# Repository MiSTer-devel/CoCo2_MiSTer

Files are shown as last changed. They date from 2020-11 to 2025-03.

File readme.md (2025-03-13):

# MiSTer Tandy Color Computer 2 (CoCo2)  and Dragon 32

Originally started by:

https://github.com/pcornier/coco2

Completeted by dshadoff, alanswx,  pcornier, shodge12, and theflynn49.
Regression tests by Kathleen.

### Tandy Color 2

This core implements a Tandy Color Computer 2 (CoCo2) including:
 * 64k Memory
 * 2 Analog Joysticks (with a swap feature)
 * Cassette Loading/Saving
 * Sound
 * Cartridge Support
 * Disk support

### Dragon 32 / 64

 * 32K Dragon32 or 64K Dragon64
 * 2 Analog Joysticks (with a swap feature)
 * Cassette Loading/Saving
 * Sound
 * Cartridge Support
 * Disk support

### ROMS

This core needs ROMS, that you may build from files you find easely on colorcomputerarchive (or elsewhere)

 * boot0.rom : 16k (CoCo2) : concatenation of extbas11.rom and bas12.rom, in this order.
 * boot1.rom : 16k (Dragon32) : copy of d32.rom
 * boot2.rom : 32k (Dragon64) concatenation of d64rom1.rom and d64rom2.rom in this order.
 * boot3.rom : 24k (Disk drivers) concatenation of disk11.rom, sdose8.rom (for D32) and sdose8.rom (for D64) again in this order.

You may use other components, these are just the ones we use to run the regression tests. You need to respect the location of the rom in the boot files, like you would respect the location of a rom chip on a motherboard.

Once you collected the needed files, you may run theses commands on your MiSTer to build the bootX.rom files :

 * cat extbas11.rom bas12.rom > /media/fat/games/CoCo2/boot0.rom
 * cp d32.rom  /media/fat/games/CoCo2/boot1.rom 
 * cat d64rom1.rom d64rom2.rom > /media/fat/games/CoCo2/boot2.rom
 * cat disk11.rom sdose8.rom sdose8.rom > /media/fat/games/CoCo2/boot3.rom

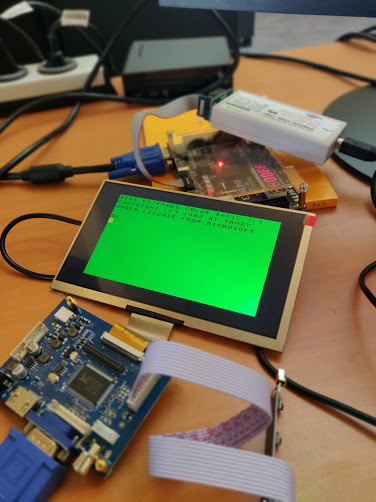
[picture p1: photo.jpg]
Coco2 running on the AX309


*Coco 2 running on a AX309 board*

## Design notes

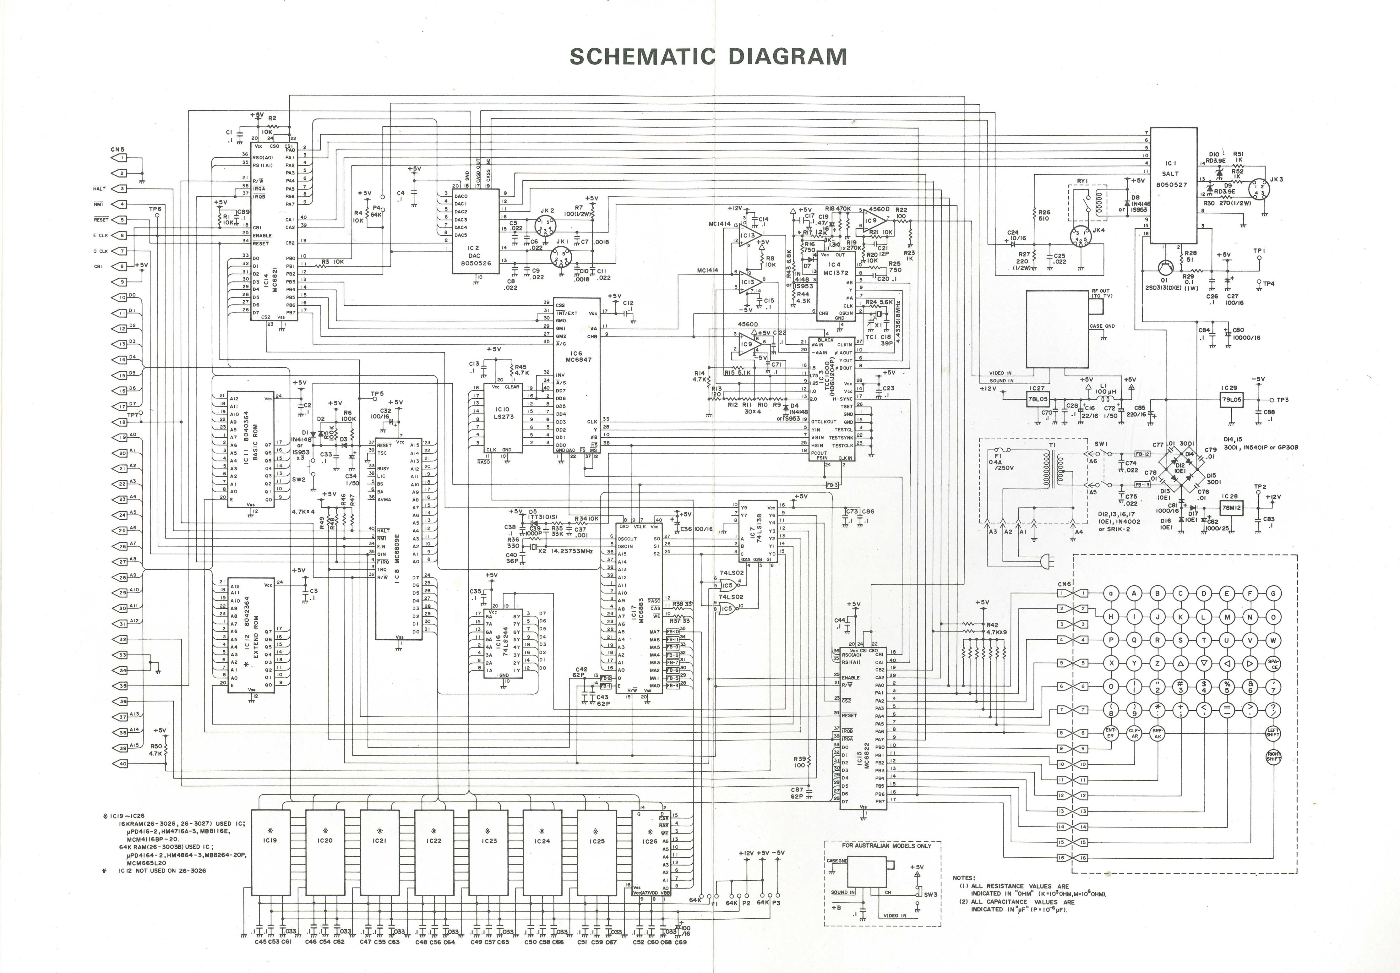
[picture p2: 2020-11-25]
doc/schematic.jpg

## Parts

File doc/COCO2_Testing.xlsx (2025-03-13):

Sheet: CoCo2
CoCo2 Compatibility Testing Spreadsheet |  |  |  |  | Version: | 3.01 |  |  |  |  |  |  | 2024-06-24
ID | Game / Program | Format |  |  | Load 20240605 | Load 20240622 | Load 20240629 | Load 20240701 | Load | Load | Load | Load 20250215 | Updated on | By | Remarks | Remarks 2 | Comments
 |  | Cart | Disk | Tape |  |  |  |  | 20241230 | 20250121 | 20250131
1 | 666 The Hounted House (2003) (Hofzets Chris) |  | X |  | Y |  |  |  |  | Y | Y | Y | 2025-02-09 | Kasurin
2 | 7 Card Stud (198x) (Tandy) |  | X |  | Y |  |  |  |  | Y | Y | Y | 2025-02-09 | Kasurin |  |  | 26-3074
3 | 7 Cards Stut (1983) (Tandy) | X |  |  | Y |  | Y | Y |  |  |  | Y | 2025-02-10 | Kasurin |  |  | 26-3074
4 | Adventure in Mythology (1985) (Saguard soft) |  | X |  | Y |  |  |  |  | Y | Y | Y | 2025-02-09 | Kasurin
5 | Andrea Coco (1985) (Saguard soft) |  | X |  | Y |  |  |  |  | Y |  | Y | 2025-02-09 | Kasurin
6 | Androne (1983) (Tandy) | X |  |  | Y |  | Y | Y |  |  |  | Y | 2025-02-09 | Kasurin | D-Pad OK | Red instead of orange (reltaed to VDG6847) | 26-3096
7 | Androne (1983) (Tandy) |  | X |  | Y |  |  |  |  | Y |  | Y | 2025-02-09 | Kasurin |  |  | 26-3096
8 | Arkanoid (1987) (Tandy) |  | X |  | Y |  |  |  |  | Y |  | Y | 2025-02-09 | Kasurin |  |  | 26-3043
9 | Arkanoid (1987) (Tandy) (Coco 1-2 version) | X |  |  | Y |  | Y | Y |  |  |  | Y | 2025-02-09 | Kasurin | D-Pad OK |  | 26-3043
10 | Art Gallery (1981) (Tandy) | X |  |  | Yx |  | Yx | Yx |  |  | Y | Y | 2025-02-11 | Kasurin | Save works now |  | 26-3061
11 | Atom (1983) (Tandy) | X |  |  | Y |  | Y | y |  |  |  | Y | 2025-02-10 | Kasurin |  |  | 26-3149
12 | Atom (1983) (Tandy) |  | X |  | Y |  |  |  |  | Y |  | Y | 2025-02-09 | Kasurin |  |  | 26-3149
13 | Audio Spectrum Analyzer (1981) (Steve Bjork) | X |  |  | Yx |  | Yx |  |  |  |  | Yx | 2025-02-10 | Kasurin | ADC Input OK output sound is bad | Hint : A/Q to activate de-activate audio out | 26-3156
14 | Backgamon (1980) (Tandy) | X |  |  | Y |  | Y | Y |  |  |  | Y | 2025-02-10 | Kasurin |  |  | 26-3059
15 | Basic Aid (1982) (Eigen Sustem) | X |  |  | Y |  | Y | Y |  |  |  | N | 2025-02-10 | Kasurin |  | Hint: CTRL key is bottom arrow
16 | Bedlam (1982) (Tandy) |  | X |  | Y |  |  |  |  | Y |  | Y | 2025-02-09 | Kasurin |  |  | 26-3312
17 | Bingo Math (1980) (Tandy) | X |  |  | Y |  | Y | Y |  |  |  | Y | 2025-02-10 | Kasurin | D-Pad OK |  | 26-3150
18 | Bingo Math (1983) (Tandy) |  | X |  | Y |  |  |  |  | Y |  | Y | 2025-02-09 | Kasurin |  |  | 26-3150
19 | Blackbeard's Island (1984) (Tom Mix Softw) |  | X |  | Y |  |  |  |  | Y |  | Y | 2025-02-09 | Kasurin
20 | Bridge Tutor (1983) (Tandy) |  | X |  | Y |  |  |  |  | Y |  | Y | 2025-02-09 | Kasurin |  |  | 26-3158
21 | Bridge Tutor I (1982) (Tandy) | X |  |  | Y |  | Y | Y |  |  |  | Y | 2025-02-10 | Kasurin |  |  | 26-3158
22 | Bustout (1981) | X |  |  | Y |  | Y | Y |  |  |  | Y | 2025-02-10 | Kasurin | D-Pad OK |  | 26-3056
23 | Caladuril - FOL (1987) (Diecom Products) |  | X |  | Y |  |  |  |  | Y |  | Y | 2025-02-09 | Kasurin | Save and load work :-)
24 | Canyon Climber (1982) (Tandy) |  | X |  | Yx |  |  | Y |  | Y |  | Y | 2025-02-09 | Kasurin | Glitches when move to next level | To be checked on real HW [Kb] | 26-3089
25 | Castle Guard (1981) (Tandy) | X |  |  | Y |  | Y | Y |  |  |  | Y | 2025-02-10 | Kasurin |  | Red instead of orange (reltaed to VDG6847) | 26-3079
26 | Castle Guard (1982) (Tandy) |  | X |  | Y |  |  |  |  | Y |  | Y | 2025-02-09 | Kasurin |  |  | 263079
27 | Cave Walker (1986) (Spectral Associates) |  | X |  | Y |  |  |  |  |  |  | Y | 2025-02-09 | Kasurin | OS-9 game. | Type DOS to start the game
28 | Cave Walker (1987) (Tandy) |  | X |  | Y |  |  |  |  |  |  | Y | 2025-02-09 | Kasurin | OS-9 game. | Type DOS to start the game | 26-3246
29 | Caves of the unwashed heaten (1996) |  | X |  | Y |  |  |  |  |  |  | Y | 2025-02-09 | Kasurin
30 | Caynon Climber (1989) | X | X |  | Yx |  | Yx |  |  |  |  | y | 2025-02-09 | Kasurin | Glitches when move to next level | To be checked on real HW [Kb] | 26-3089
31 | Checker King (1980) (Tandy) | X |  |  | Y |  | Y | Y |  |  |  | y | 2025-02-09 | Kasurin |  |  | 26-3055
32 | Checker King (1980) (Tandy) |  | X |  | Y |  |  |  |  |  |  | Y | 2025-02-09 | Kasurin |  |  | 26-3055
33 | Checkers (1986) (Young Richard) |  | X |  | Y |  |  |  |  |  |  | y | 2025-02-09 | Kasurin | Hint : cload "C for tape | Hint : cload "D for disk
34 | Chess (1980) (Tandy) |  | X |  | Y |  |  |  |  |  |  | Y | 2025-02-09 | Kasurin |  |  | 26-3050
35 | Chessd (1984) (Software Dynamicc) |  | X |  | Y |  |  |  |  |  |  | Y | 2025-02-09 | Kasurin
36 | Clowns & Ballons (1982) (Tandy) | X |  |  | Y |  | Y | Y |  |  |  | Y | 2025-02-09 | Kasurin |  | Red instead of orange (reltaed to VDG6847) | 26-3087
37 | Clowns & Ballons (1982) (Tandy) |  | X |  | Y |  |  |  |  |  |  | Y | 2025-02-09 | Kasurin |  |  | 26-3087
38 | Color Backgamon (1980) (Tandy) |  | X |  | Y |  |  |  |  |  |  | Y | 2025-02-09 | Kasurin |  |  | 26-3059
39 | Color Baseball (1980) (Tandy) | X |  |  | Y |  | Y | Y |  |  |  | Y | 2025-02-10 | Kasurin |  |  | 26-3095
40 | Color Cubes (1981) (Tandy) | X |  |  | Y |  | Y | Y |  |  |  | Y | 2025-02-10 | Kasurin |  |  | 26-3075
41 | Color Cubes (1981) (Tandy) |  | X |  | Y |  |  |  |  |  |  | Y | 2025-02-09 | Kasurin |  |  | 26-3075
42 | Color File (1981) (Tandy) | X |  |  | Y |  | Y | Y |  |  |  | Y | 2025-02-10 | Kasurin | Load and save from tape works ! |  | 26-3103
43 | Color File II (1986) (Tandy) | X |  |  | Y |  | Y | Y |  |  |  | Y | 2025-02-10 | Kasurin | Load and save from tape works ! | Hint: HOME + 1,2,3….. for selection | 26-3110
44 | Color Forth (1981) (Microworks) | X |  |  | Y |  | Y | y |  |  |  | Y | 2025-02-10 | Kasurin
45 | Color Logo (1983) (Tandy) | X |  |  | Y |  | Y | Y |  |  |  | Y | 2025-02-10 | Kasurin | Save doesn't work |  | 26-2722
46 | Color Robot Battle (1981) (Tandy) | X |  |  | Y |  | Y | Y |  |  |  | Y | 2025-02-10 | Kasurin | Seems to work | Red instead of orange (reltaed to VDG6847) | 26-3070
47 | Color Scripsit (1981) (Tandy) | X |  |  | Yx |  | Yx | Yx |  |  |  | Y | 2025-02-10 | Kasurin | Load and save from tape works ! | Hint: ESC+1 for main menu | 26-3105
48 | Color Scripsit II (1986) (Tandy) | X |  |  | Yx |  | Yx | Yx |  |  |  | Y | 2024-07-02 | Kasurin |  | No experience with this software | 26-3109
49 | Conquering Armies (1988) (Mitchell Soft.) |  | X |  | N |  |  |  |  | N | Y | Y | 2025-02-09 | Kasurin | Seems to be working | No experience with this software
50 | Cosmic Crusader (Blaby) (Coco Port) |  | X | X |  |  | N | N |  |  | Y | Y | 2025-02-02 | Kasurin | Disk seems to be working fine | Tape to be tested
51 | Crosswords (1981) (Tandy) | X |  |  | Y |  | Y | Y |  |  |  | Y | 2025-02-10 | Kasurin |  |  | 26-3082
52 | Cyrus Chess (1982) (Tandy) |  | X |  | Y |  |  |  |  |  |  | Y | 2025-02-09 | Kasurin |  |  | 26-3064
53 | Cyrus World Class Chess (1983) (Tandy) | X |  |  | Y |  | Y | Y |  |  |  | Y | 2025-02-10 | Kasurin |  |  | 26-3064
54 | Dallas Quest (1984 (Tandy) |  | X |  | Y |  |  |  |  |  |  | Y | 2025-02-09 | Kasurin |  |  | 26-3294
55 | Demolition Derby (1984) (Tandy) | X |  |  | Y |  | Y |  |  |  |  | Y | 2025-02-10 | Kasurin |  | Red instead of orange (reltaed to VDG6847) | 26-3044
56 | Demon Attack (1984) (Tandy) | X |  |  | Y |  | Y |  |  |  |  | Y | 2025-02-10 | Kasurin |  | Red instead of orange (reltaed to VDG6847) | 26-3099
57 | Demon Attack (1984) (Tandy) |  | X |  | Y |  |  |  |  |  |  | Y | 2025-02-09 | Kasurin |  |  | 26-3099
58 | Desert Rider (1984) (Tandy) |  | X |  | N |  |  |  | Yx | Yx | Yx | Yx | 2025-02-02 | Kasurin | Works but vertical position issue | when jumping 24-01-2025 | 26-3292
59 | Diagnostics (1980) (Tandy) | X |  |  | Y |  | Y |  |  |  |  | Y | 2025-02-10 | Kasurin |  |  | 26-3019
60 | Diagnostics v2.0) (1982) (Tandy) | X |  |  | Y |  | Y |  |  |  |  | Y | 2025-02-10 | Kasurin |  |  | 26-3019
61 | Dino Wars (1980) (Tandy) |  | X |  | Y |  |  |  |  |  |  | Y | 2025-02-10 | Kasurin |  |  | 26-3057
62 | Dinowars (1981) (Tandy) | X |  |  | Y |  | Y |  |  |  |  | Y | 2025-02-10 | Kasurin |  |  | 26-3057
63 | Direct Connect Model Pak (1985) (Tandy) | X |  |  | Y |  | Y |  |  |  |  | Y | 2025-02-10 | Kasurin | Supposed to be OK | No ways to test | 26-2228
64 | Don-Pan (1984) (Tandy) | X |  |  | Y |  | Y |  |  |  |  | Y | 2025-02-10 | Kasurin |  |  | 26-2228
65 | Donu Dilemma (1987) (Marentes, Nikolas) |  | X |  | Y |  |  |  |  |  |  | Y | 2025-02-09 | Kasurin |  |  | 26-9649
66 | Doodle Bug (1982) (Computer Ware) | X |  |  | Y |  | Y |  |  |  |  | Y | 2025-02-10 | Kasurin |  | Red instead of orange (reltaed to VDG6847)
67 | Doodle Bug (1982) (Computer Ware) (Buff) | X |  |  | Y |  | Y |  |  |  |  | Y | 2025-02-10 | Kasurin
68 | Doodle Bug (1982) (Computer Ware) (Green) | X |  |  | Y |  | Y |  |  |  |  | Y | 2025-02-10 | Kasurin
69 | Doubleback (1982) (Tandy) | X |  |  | Y |  | Y |  |  |  |  | Y | 2025-02-10 | Kasurin |  | Red instead of orange (reltaed to VDG6847) | 26-3091
70 | Doubleback (1982) (Tandy) |  | X |  | Yx |  |  |  | Y | Y |  | Y | 2025-02-09 | Kasurin |  |  | 26-3091
71 | Dounwland (1984) (Tandy) |  | X |  | Y |  |  |  |  |  |  | Y | 2025-02-09 | Kasurin |  |  | 26-3046
72 | Downloand v1,0 (1983) (Tandy) | X |  |  | Y |  |  |  |  |  |  | Y | 2025-02-10 | Kasurin |  | Red instead of orange (reltaed to VDG6847) | 26-3046
73 | Downloand v1,1 (1983) (Tandy) | X |  |  | Y |  |  |  |  |  |  | Y | 2025-02-10 | Kasurin |  | Red instead of orange (reltaed to VDG6847) | 26-3046
74 | Dragon fire (1984) (Tandy) | X |  |  | N |  | Y | Y | y | y |  | Y | 2025-02-10 | Kasurin | Corrupted graphics [20240605] | Runs fine with [20240629] | 26-3098
75 | Dragonfire (1982) (Tandy) |  | X |  | N |  |  | Y | y | y |  | Y | 2025-02-09 | Kasurin | Corrupted graphics [20240605] | Runs fine with [20240701] | 26-3098
76 | Dungeons of Daggorath (1982) (Tandy) | X |  |  | Y |  | Y |  |  |  |  | Y | 2025-02-10 | Kasurin |  | Red instead of orange (reltaed to VDG6847) | 26-3093
77 | EDTASM+ (1982) (Tandy) | X |  |  | Y |  | Y |  |  |  |  | Y | 2025-02-10 | Kasurin |  |  | 26-3250
78 | Facemaker (1984) (Spinnaker) | X |  |  | Y |  | Y |  |  |  |  | Y | 2025-02-10 | Kasurin |  |  | 26-3166
79 | Flight Simulator I (1984) (Tandy) |  | X |  | Y |  |  |  |  |  |  | Y | 2025-02-09 | Kasurin | Seems to work | No experience with this game | 26-3108
80 | Football (1980) (Tandy) | X |  |  | Y |  | Y |  |  |  |  | Y | 2025-02-10 | Kasurin | Seems work | No experience with this game | 26-3053
81 | football (1980) (Tandy) |  | X |  | Y |  |  |  |  |  |  | Y | 2025-02-09 | Kasurin |  |  | 26-3053
82 | Fraction Fever (1984) (Tandy) | X |  |  | Yx |  | Yx |  | Yx | Yx | Yx | YX | 2025-02-10 | Kasurin | Works with kbd, but not with joystick |  | 26-3169
83 | Galactic Attack (1982) (Tandy) | X |  |  | Y |  | Y |  |  |  |  | Y | 2025-02-10 | Kasurin |  |  | 26-3066
84 | Ghana Bwana (1984) (Tandy) |  | X |  | Y |  |  |  |  |  |  | Y | 2025-02-09 | Kasurin |  |  | 26-3293
85 | Gin Champion (1982) (Tandy) | X |  |  | Y |  | Y |  |  |  |  | Y | 2025-02-10 | Kasurin |  |  | 26-3083
86 | Gin Champion (1982) (Tandy) |  | X |  | Y |  |  |  |  |  |  | Y | 2025-02-09 | Kasurin |  |  | 26-3083
87 | Gomoku-Renju (1983) (Tandy) | X |  |  | Y |  | Y |  |  |  |  | Y | 2025-02-10 | Kasurin |  |  | 26-3069
88 | Gomoku-Renju (1983) (Tandy) |  | X |  | Y |  |  |  |  |  |  | Y | 2025-02-09 | Kasurin |  |  | 26-3069
89 | Graphic Pak (1982) (Tandy) | X |  |  | Yx |  | Yx |  |  |  |  | Y | 2024-07-01 | Kasurin | Load and save from tape works ! |  | 26-3157
90 | Handyman (1981) (Tandy) | X |  |  | Y |  | Y |  |  |  |  | Y | 2025-02-10 | Kasurin |  |  | 26-3154
91 | Kids on Keys (1984) (Spinnaker) | X |  |  | Y |  | Y |  |  |  |  | Y | 2025-02-10 | Kasurin |  | Red instead of orange (reltaed to VDG6847) | 26-3167
92 | Kindercomp (1984) (Spinnaker) | X |  |  | Y |  | Y |  |  |  |  | Y | 2024-07-01 | Kasurin |  |  | 26-3168
93 | Klendathu (198x) (Tandy) |  | X |  | N |  |  |  | N | N | Y | Y | 2025-02-09 | Kasurin | Hint : HOME to start the game |  | 26-2567
94 | Madness and the Minotaur (1982) (Tandy) |  | X |  | Y |  |  |  |  |  |  | Y | 2025-02-09 | Kasurin |  |  | 26-3313
95 | Math Tutor (1988) (Tandy) | X |  |  | N |  | N |  | N | N | N | N | 2025-02-10 | Kasurin | Keys not respondig / Wrong colors | Red instead of orange (reltaed to VDG6847) | 26-3148
96 | Mega-Bug (1982) (Tandy) | X |  |  | Y |  | Y |  |  |  |  | Y | 2025-02-11 | Kasurin |  | Red instead of orange (reltaed to VDG6847) | 26-3076
97 | Micro Chess v2.0 (1980) (Tandy) | X |  |  | Y |  | Y |  |  |  |  | Y | 2025-02-11 | Kasurin |  |  | 26-3050
98 | Micro Painter (1982) (Tandy) | X |  |  | Y |  | Y |  |  |  |  | Y | 2024-07-01 | Kasurin |  |  | 26-3077
99 | Microbes (1981) (Tandy) | X |  |  | Y |  | Y |  |  |  |  | Y | 2025-02-11 | Kasurin |  | Red instead of orange (reltaed to VDG6847) | 26-3085
100 | Microbes (1981) (Tandy) |  | X |  | Y |  |  |  |  |  |  | Y | 2025-02-09 | Kasurin |  |  | 26-3085
101 | Mind-Roll (1989) (Tandy) |  | X |  | Y |  |  |  |  |  |  | Y | 2025-02-09 | Kasurin |  |  | 26-3100
102 | Monster Maze (1981) (Tandy) |  | X |  | Y |  |  |  |  |  |  | Y | 2025-02-09 | Kasurin |  |  | 26-3081
103 | Monster Maze (1983) (Tandy) | X |  |  | Y |  | Y |  |  |  |  | Y | 2025-02-11 | Kasurin |  | Red instead of orange (reltaed to VDG6847) | 26-3081
104 | Music (1980) (Tandy) | X |  |  | Y |  | Y |  |  |  |  | Y | 2025-02-11 | Kasurin |  |  | 26-3151
105 | Nerble Force (Computeware) |  | X |  |  |  | Y | Y |  |  |  | Y | 2025-02-11 | Kasurin
106 | One On One (1983) (Tandy) |  | X |  | Y |  |  |  |  |  |  | Y | 2025-02-09 | Kasurin |  |  | 26-3288
107 | Orchestra 90-CC (1984) (Tandy) | X |  |  | Y |  | Y |  |  |  |  | Y | 2025-02-11 | Kasurin | Start | No experience with this program | 26-3143
108 | Panic Button (1983) (Tandy) | X |  |  | Y |  | Y |  |  |  |  | Y | 2025-02-11 | Kasurin |  | Red instead of orange (reltaed to VDG6847) | 26-3147
109 | Panic Button (1985) (Tandy) |  | X |  | Y |  |  |  |  |  |  | Y | 2025-02-09 | Kasurin
110 | Pegasus and the phantom rider (1985) |  | X |  | Y |  |  |  |  |  |  | Y | 2025-02-09 | Kasurin
111 | Personal Finance (1980) (Tandy) | X |  |  | Yx |  | Yx |  |  |  | Yx | Yx | 2025-02-11 | Kasurin | Load and save data don't seem to work | Need more testing to confirm | 26-3101
112 | Personal Finance II (1983) (Tandy) | X |  |  | Yx |  | Yx |  |  |  |  | Yx | 2025-02-11 | Kasurin | Load and save data don't seem to work | Need more testing to confirm | 26-3106
113 | Pinball (1980) (Tandy) | X |  |  | Y |  | Y |  |  |  |  | Y | 2025-02-11 | Kasurin |  | Hint : Need two Joysticks to play | 26-3052
114 | Pinball (1980) (Tandy) |  | X |  | y |  |  |  |  |  |  | Y | 2025-02-09 | Kasurin |  | Hint : Need two Joysticks to play | 26-3052
115 | Pitfall II (1985) (Tandy) |  | X |  | Y |  |  |  |  |  |  | y | 2025-02-09 | Kasurin |  | Had to use the ALT2 version | 26-3287
116 | Polaris (1981) (Tandy) | X |  |  | Y |  | Y |  |  |  |  | Y | 2025-02-11 | Kasurin |  | Hint : ZXC for fire + joystick | 26-3065
117 | Polaris (1981) (Tandy) |  | X |  | Y |  |  |  |  |  |  | y | 2025-02-09 | Kasurin |  | Hint : ZXC for fire + joystick | 26-3065
118 | Poltergeist (1982) (Tandy) | X |  |  | Y |  | Y |  |  |  |  | Y | 2025-02-11 | Kasurin |  | Red instead of orange (reltaed to VDG6847) | 26-3073
119 | Popcorn (1981) (Tandy) | X |  |  | Y |  | Y |  |  |  |  | Y | 2025-02-11 | Kasurin |  | Red instead of orange (reltaed to VDG6847) | 26-3090
120 | Pooyan |  | X |  |  |  |  |  |  |  |  | y | 2025-02-09 | Kasurin
121 | Project Nebula (1981) (Tandy) | X |  |  | Y |  | Y |  |  |  |  | Y | 2025-02-11 | Kasurin |  |  | 26-3063
122 | Quasar Commander (1980) (Tandy) | X |  |  | Y |  | Y |  |  |  |  | Y | 2025-02-11 | Kasurin |  | Hint : Needs to joysticks to play | 26-3051
123 | Reactoid (1983) (Tandy) | X |  |  | Y |  | Y |  |  |  |  | Y | 2025-02-11 | Kasurin |  | Red instead of orange (reltaed to VDG6847) | 26-3092
124 | Roman Checkers (1981) (Tandy) | X |  |  | Y |  | Y |  |  |  |  | Y | 2025-02-11 | Kasurin |  |  | 26-3071
125 | SDS80C (1981) (The Micro Works) | X |  |  | Y |  | Y |  |  |  |  | Y | 2025-02-11 | Kasurin
126 | Shooting Gallery (1982) (Tandy) | X |  |  | Y |  | Y |  |  |  |  | Y | 2025-02-11 | Kasurin |  | Red instead of orange (reltaed to VDG6847) | 26-3088
127 | Skiing (1981) (Tandy) | X |  |  | Y |  | Y |  |  |  |  | Y | 2025-02-11 | Kasurin |  |  | 26-3058
128 | Slay The Nereis (1983) (Tandy) | X |  |  | Y |  | Y |  |  |  |  | Y | 2025-02-11 | Kasurin |  | Red instead of orange (reltaed to VDG6847) | 26-3086
129 | Soko Ban (1988) (Tandy) | X |  |  | Y |  | Y |  |  |  |  | Y | 2025-02-11 | Kasurin |  | Red instead of orange (reltaed to VDG6847) | 26-3161
130 | Space Assault (1981) (Tandy) | X |  |  | Y |  | Y |  |  |  |  | Y | 2025-02-11 | Kasurin |  |  | 26-3060
131 | Spectaculator (1983) (Tandy) | X |  |  | Y |  | Y |  |  |  |  | Y | 2025-02-11 | Kasurin |  |  | 26-3104
132 | Spidercide (1983) (Tandy) | X |  |  | Y |  | Y |  |  |  |  | Y | 2024-07-01 | 2025-02-11 |  | Red instead of orange (reltaed to VDG6847) | 26-3049
133 | Starblaze (1983) (Tandy) | X |  |  | Y |  | Y |  |  |  |  | Y | 2025-02-11 | Kasurin |  |  | 26-3094
134 | Stellar Lifeline (1983) (Tandy) | X |  |  | Y |  | Y |  |  |  |  | Y | 2025-02-11 | Kasurin |  | Red instead of orange (reltaed to VDG6847) | 26-3047
135 | Super Logo (1984) (Tandy) | X |  |  | Y |  | Y |  |  |  |  | Y | 2025-02-11 | Kasurin |  | Hint : Artifact to be disabled | 26-2717
136 | Temple of ROM (1984) (Tandy) | X |  |  | Y |  | Y |  |  |  |  | y | 2025-02-11 | Kasurin |  | Red instead of orange (reltaed to VDG6847) | 26-3045
137 | Tennis (1981) (26-3080) (Tandy) | X |  |  | Y |  | Y |  |  |  |  | Y | 2025-02-11 | Kasurin |  |  | 26-3080
138 | TypeMate (1988) (Tandy) | X |  |  | N |  | N |  | N | N | N | N | 2025-02-11 | Kasurin | Keys not respondig as they should |  | 26-3155
139 | Typing Tutor (1980) (Tandy) | X |  |  | Y |  | Y |  |  |  |  | Y | 2025-02-11 | Kasurin |  |  | 26-3152
140 | Videotex v1,1 (1981) (Tandy) | X |  |  | Y |  | Y |  |  |  |  | Y | 2025-02-11 | Kasurin | Supposed to be OK | No experience with this program | 26-2222
141 | Videotex v1,2 (1981) (Tandy) | X |  |  | Y |  | Y |  |  |  |  | Y | 2025-02-11 | Kasurin | Supposed to be OK | No experience with this program | 26-2222
142 | Wildcatting (1982) (Tandy) | X |  |  | Y |  | Y |  |  |  |  | Y | 2025-02-11 | Kasurin |  |  | 26-3067
143 | OS9 Level 1 V 01.00.00 |  | X |  |  |  |  |  |  |  |  | Y | 2025-03-12 | SRH
144 | NitrOS-9/6809 Level 1 V3.30 for CoCo1 |  | X |  |  |  |  |  |  |  |  | Y | 2025-03-12 | SRH
145 | NitrOS-9/6809 Level 1 V3.30 for CoCo2 |  | X |  |  |  |  |  |  |  |  | Y | 2025-03-12 | SRH

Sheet: Dragon32
CoCo2 Compatibility Testing Spreadsheet |  | Version: | 3.01 |  | 2024-06-24
ID | Format / Name | Cat n° | Load 20250131 | Load 20250215 | Updated on | By | Remarks | Remarks 2
1 | DSK / Airball |  | Y | Y | 2025-02-18 | Kasurin
2 | DSK / Balldozer |  | Y | Y | 2025-02-18 | Kasurin
3 | CAS / 4D Romik Cube |  |  | Y | 2025-02-18 | Kasurin
4 | CAS / Adventure 2 - Jerusalem |  |  | Y | 2025-02-18 | Kasurin
5 | CAS / Air Assault |  |  | Y | 2025-02-18 | Kasurin
6 | CAS / Alcatraz |  |  | Y | 2025-02-18 | Kasurin
7 | CAS / Amazing |  |  | Y | 2025-02-18 | Kasurin
8 | DSK / Machine Languae Tutorial |  |  | Y | 2025-02-19 | Kasurin | Need a complete reload of the core otherwise the screen is not OK at restart
9 | CAS / Phantom Slayer( (Med System) |  |  | N | 2025-02-20 | Kasurin | Load but ST ERROR after EXEC
10 | CAS / Backtrack (198x) |  |  | Y | 2025-02-20 | Kasurin
11 | CAS / The Bells (1984) |  |  | Yx | 2025-02-20 | Kasurin | Works with some glitches | Need SHIFT+Z/W for left/right instead od Z/W
12 | CAS / Chuckie egg (1983) |  |  | Y | 2025-02-20 | Kasurin
13 | CAS / Ice Castles |  |  | Y | 2025-02-20 | Kasurin | Works with joystick :-)
14 | CAS / Space Invaders |  |  | Y | 2025-02-20 | Kasurin
15 | CAS / Time Bandid |  |  | N | 2025-02-20 | Kasurin | Freeze during loading
16 | CAS / Tube way army |  |  | Yx | 2025-02-20 | Kasurin | Does not work with joystick | Strange key mapping
17 | CAS / UGH! |  |  | Y | 2025-02-20 | Kasurin | Works with joystick :-)
18 | DSK / Interplanetary Trader |  |  | y | 2025-03-07 | Kasurin
19 | DSK / Execution |  |  | Y | 2025-03-07 | Kasurin
20 | DSK / Wumpus Mantion |  |  | Y | 2025-03-07 | Kasurin
21 | DSK / Wipeout |  |  | Y | 2025-03-07 | Kasurin
22 | DSK / Frogger |  |  | Y | 2025-03-07 | Kasurin
23 | DSK / Flipper |  |  | Y | 2025-03-07 | Kasurin
24 | DSK / Raceball |  |  | Y | 2025-03-07 | Kasurin
25 | DSK / Cuthbert in the jungle |  |  | Y | 2025-03-07 | Kasurin
26 | DSK / Pedro |  |  | Y | 2025-03-07 | Kasurin
27 | DSK / Transylvanian Tower |  |  | Yx | 2025-03-07 | Kasurin | Seems to be working | Did not find how to control the player
28 | DSK / Danger Ranger |  |  | Y | 2025-03-07 | Kasurin
29 | DSK / Shock Trooper |  |  | Y | 2025-03-07 | Kasurin
30 | DSK / Speed Racer |  |  | Y | 2025-03-07 | Kasurin
31 | DSK / Storm Arrows |  |  | Yx | 2025-03-07 | Kasurin | Car moves always to right | Like if Joy is not centered
32 | DSK / Chuckie Egg |  |  | Y | 2025-03-07 | Kasurin
33 | DSK / Moon Hopper |  |  | Yx | 2025-03-07 | Kasurin | Not possible to move L&R
34 | DSK / The Phantom Slayer |  |  | Y | 2025-03-07 | Kasurin
35 | DSK / Hunchback |  |  | Yx | 2025-03-07 | Kasurin | Strange diagonal lines in game
36 | DSK / Morocco GP |  |  | Y | 2025-03-07 | Kasurin
37 | DSK / Juniors Revenge |  |  | Y | 2025-03-07 | Kasurin
38 | DSK / U X B |  |  | Y | 2025-03-07 | Kasurin | Seems to be working | No experience with this game
39 | DSK / Intergalactic force |  |  | Y | 2025-03-07 | Kasurin
40 | DSK / Dragon Hawk |  |  | Y | 2025-03-07 | Kasurin
41 | DSK / Cuthbert in space |  |  | Y | 2025-03-07 | Kasurin
42 | DSK / Beanstalker |  |  | y | 2025-03-07 | Kasurin
43 | DSK / Creazy Painter |  |  | Y | 2025-03-07 | Kasurin
44 | DSK / Talking Android Attack |  |  | Y | 2025-03-07 | Kasurin
45 | DSK / Rommels Revenge |  |  | Y | 2025-03-07 | Kasurin | Didn't find with kybd how to move forward and backward | Works with Joystick however
46 | DSK / Cashman |  |  | Y | 2025-03-07 | Kasurin
47 | DSK / The King |  |  | Y | 2025-03-07 | Kasurin
48 | DSK / Eddy Steady Go |  |  | N | 2025-03-07 | Kasurin | Does not launch
49 | DSK / TeaTime |  |  | Y | 2025-03-07 | Kasurin
50 | DSK / Cuthbert in golden chalice |  |  | Yx | 2025-03-07 | Kasurin | Works but 2 lines which shouldn't be there | at the top left and righ of the screen during the game
51 | DSK / Starman Jones |  |  | Y | 2025-03-07 | Kasurin
52 | DSK / Robin hood |  |  | Y | 2025-03-07 | Kasurin
53 | DSK / Time Bandit |  |  | Y | 2025-03-07 | Kasurin
54 | DSK / Space Wrek |  |  | Y | 2025-03-07 | Kasurin
55 | DSK / Pitfiend |  |  | Y | 2025-03-07 | Kasurin
56 | DSK / BoulderCrash |  |  | Y | 2025-03-07 | Kasurin
57 | DSK / Chambers |  |  | Y | 2025-03-07 | Kasurin
58 | DSK / Kamacarzy |  |  | Y | 2025-03-07 | Kasurin
59 | DSK / Tube Way Army |  |  | Y | 2025-03-07 | Kasurin
60 | DSK / Wizards Quest |  |  | Y | 2025-03-07 | Kasurin
61 | DSK / Dragon Chess |  |  | Y | 2025-03-07 | Kasurin
62 | DSK / Dungeon Raid |  |  | Y | 2025-03-07 | Kasurin
63 | DSK / Stone Raider II |  |  | Y | 2025-03-07 | Kasurin
64 | DSK / Draconian |  |  | Y | 2025-03-07 | Kasurin
65 | DSK / Moon Cresta |  |  | Y | 2025-03-07 | Kasurin
66 | DSK / Blochead |  |  | N | 2025-03-07 | Kasurin | Doesn't go further than color selection
67 | DSK / BoulderCrash II |  |  | Y | 2025-03-07 | Kasurin
68 | DSK / Buzzard bait |  |  | Y | 2025-03-07 | Kasurin
69 | DSK / Zaxxon |  |  | Y | 2025-03-07 | Kasurin
70 | DSK / Guardian |  |  | N | 2025-03-07 | Kasurin | Playable but graphic garbage
71 | DSK / Whirlybird run |  |  | Y | 2025-03-07 | Kasurin
72 | DSK / Paper Route |  |  | Y | 2025-03-07 | Kasurin
73 | DSK / Marble Maze |  |  | Y | 2025-03-07 | Kasurin
74 | DSK / Color Tenis |  |  | Y | 2025-03-07 | Kasurin

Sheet: Dragon64
CoCo2 Compatibility Testing Spreadsheet |  | Version: | 3.01 | 2024-06-24
ID | Format / Name | Cat n° | Load 20250215 | Updated on | By | Remarks | Remarks 2
1 | NitrOS-9/6809 Level 1 V3.30 for Dragon64 |  | Y | 2025-03-11 | SRH | You may want to turn artifacts off

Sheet: Version History
CoCo2 Compatibility Testing Spreadsheet |  |  |  | Version: | 3.01 | 2024-06-24
Version | Date | Comment
3.01 | 2024-06-24 | Headers slaved to CoCo2_Cart, version hostory added, Version and Version_Date derrived from Version History table
Current Version: |  | 3.01 | 2024-06-24

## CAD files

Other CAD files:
ints.stp
stp1.stp

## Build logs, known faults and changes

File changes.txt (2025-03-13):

CoCo2_20250215 - 001 RC6
1:	Recursion testing spreadsheet completed.
2:	Updated MiSTer template
3:	Added Daily Build Number.  Note sys/build_num.tcl changed to add this functionality.
	Updating the template in the future will need to restore this version to prevent
	the loss of this functtion.
4:  Changed back to Cycle accurate 09
5:  Fixed Timer [The FDC cartridge does not generate a FIRQ when asserted.  This was fixed..]
6:  Double speed poke in the SAM via SAM registers coded.  Video sync at high speed fixed
7:  FDC changed to use system clk and divide to 8 Mhz changed to /6.  FIRQ generation
    for Dragon, qualified enabled only in Dragon configurations.
8:	Fixed some incorrect menu subscript duplications
9:	Added Cassette Save
10: Added minor delay to 1793 interrupt to fix dragon os9 problem.  Also removed HALT from
    dragon FDC.
11: Nitro OS9 working on CoCo & Dragon64.
12:	ROMs removed from .rbf.  Instructions for the creation in the README.MD file.  Code added
    to show 'NO ROMS' on output video without roms being found on load of core.

To Do...

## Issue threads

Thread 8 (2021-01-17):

Controller issue

Televicious, 2021-01-17:
I've tried several controllers and up an down do not work. Running color baseball. Also, color baseball is the only cart that loads dungeon of dagorath does not. The work in the coco3 core, though that care wo"t read disk images properly.

alanswx, 2021-01-17:
Make sure you go completely through the analog joystick setup. This core uses an analog joystick. Also check to see if the analog joystick works on another analog core like food fight or lunar lander.

dshadoff, 2021-01-17:
It's actually a problem that the analog stick setup is misleading; as you sequence through the controller setup, analog stick setup takes place after mouse settings.

sorgelig, 2021-01-17:
How it's misleading?

dshadoff, 2021-01-17:
I will work on D-Pad emulation of analog joysticks, as analog joystick setup is a common issue.

With respect to the other compatibility concerns, we can look into the Dungeons of Daggorath at some point.
This core does not currently support disk, or CoCo3 hardware, so please be careful about compatibility.

dshadoff, 2021-01-18:
I ran the Dungeons of Daggorath cart from the "TRS-80 Color Computer Archive" successfully on the existing core.
Not sure what problems you are seeing.

That game is, however, an adventure game where you need to type specific commands, so it isn't obvious how to play if you're not already familiar with it.

Also, I have submitted a pull request to use D-pad in case you are still having difficulties setting up the analog stick.  It will be part of the next release when it becomes available.

Televicious, 2021-01-18:
It was not loading for me even after resetting. The .ccc was from the same
archive. I'll redownload it and try again incase the file was somegow
corrupted. Good to know on the analog pad. I can use an analog stick. I
thought this project to be similar to the coco3 core that was released on
mister last spring. That had the dpad emulation already.

On Sun, Jan 17, 2021, 11:04 PM David Shadoff <notifications@github.com>
wrote:

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

dshadoff, 2021-01-18:
That CoCo3 core has several years of development behind it; this core was built in the fall independently, and doesn't have all the features at this time.

The "Reset" on this core is not 100% perfect; indeed, it isn't perfect on the original hardware either - but this core needs to stabilize the reset a bit more than it currently is.  If reset (or insert cartridge) doesn't work for you, try another reset.  It is a bit finicky at the moment.

dshadoff, 2021-01-25:
The version with the d-pad emulation of analog pad is now released; I'm hoping by now you have also straightened out your issues setting up the analog pad, and have tested it works - for example, with the "Diagnostics 2.0" cartridge.

I would request that you close the issue if this is the case.
If you have other issues, please open separate issues in the log so that they can be tracked properly.

Televicious, 2021-01-25:
Oh awesome. Yes, it works great. Thank you.

Closed 2021-01-25.

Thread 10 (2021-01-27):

Flickering picture since the last update

Milongero71, 2021-01-27:
Hello,
with the last update of the cores
Atari ST, GameBoy, Coco2 and ZX Spectrum I have now a flicker in the picture and OSD. I used a LCD monitor via the analog output on the I/O board. I have activated the scaler.
I have tested the previous versions and they give a clean picture.

sorgelig, 2021-01-27:
will be fixed soon

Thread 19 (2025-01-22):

I propose to merge 022024-Changes into master

theflynn49, 2025-01-22:
@shodge12

Hello.
The title says it all.
I think this branch has reached its goals (but only shodge12 can confirm this), and the branch is getting cumbersome.
Reset, video clock, FDC are fixed, at least to some extent, the master clock change to 57Mhz seems to work fine.

What's left to do in this core in my opinion is to boot OS9 and NOS9 (today it freezes, so there must be more bugs in the fdc), add save states (to help debugging, but everyone likes them anyway), make some cleaning and warning removing, (and maybe add a skin).

So if someone feels competent to help with this decision, you're welcome :D  ...

Rgds
jF

shodge12, 2025-01-23:
@theflynn49

Not sure what is defined by cumbersome unless someone else wants to work the remaining issues.

The branch indeed makes some largescale updates to the coco2 core, but while the majority of the goals were achieved, 1 goal and 1 interrupt problem kept the merge from occurring in the 8/24 time frame.   The following is the current change log for the branch:

CoCo2_20240701 - 008
1:	Prelim recursion testing spreadsheet completed.
2:	Updated MiSTer template
3:	Added Daily Build Number.  Note sys/build_num.tcl changed to add this functionality.
	Updating the template in the future will need to restore this version to prevent
	the loss of this functtion.
4:  Change back to Cycle accurate 09
5:  Fixed Timer [The FDC cartridge does not generate a FIRQ when asserted.  This was fixed..]
6:  Preliminary double speed poke in the SAM via SAM registers coded.  WIP
7:  FDC changed to use system clk and divide to 8 Mhz changed to /6.  FIRQ generation
    for Dragon, qualified enabled only in Dragon configurations.

Issues:
1:  Highspeed pokes may be backwards.  Full 1.78Mhz seems to have a video issue.
2:  Timer basic function is not working... [interrupt processing issue]

To Do...
1:    Add Cassette Save
2:    Get FDC working for dragon (edited)

Issue 2 is a major incompatibility issue and needs to be fixed.  To do #1 is a somewhat simple rip from the CoCo3 codebase and
add here.  IMHO the dragon / OS9  issues can be left open.

I have had some personal medical issues including a recent broken leg which have been taking my available time.  I still plan on returning to these activities.

However, if there are people who wish to take over these activities, I will resync adding the most recent compatibility worksheet and re-merge the changes.

Let me know your thoughts...

-Stan

theflynn49, 2025-01-23:
@shodge12 Thank you for your fast and long answer. I should have tried to contact you long ago instead of wandering alone in the code :)

First, let me wish you a prompt and complete recovery for your health problems.

Secondly, I wish to state that @alanswx asked me to have a look at the Dragon32 FDC  to make it work (because I guess he saw me fixing the TRS80 model I), without much more details about it, and I already made a few commits in your 022024-Changes branch (I am not sure you have seen this)

What I fixed is :
- replaced E7T controller by the Dragon E8 one, fix FIRQ which must go through the PIO (DOS polls it and don't use interrupts) and the Dragon FDC clocking (1.5Mhz instead of 8)
- froze the video frequency.
- fixed the CPU reset
- fixed some vhdl clocking I didn't like, but that probably didn't change anything.
- I messed around too much with the code, it needs more cleaning.

In a way, I satisfied alan's request, and I choose to do it from your branch, because I felt the modifications in it were the best version.

So from this point, what I meant by "cumbersome" is that it is uneasy to commit in a side branch and add an image in the main one each time, if I had to go on with the core evolution. In my opinion, as it is now the branch is mature enough to become the main one (especially if some feedback by users confirms this)

But I read that you intent is to come back to maintain the core, (and as you should know that I never used a 6809 nor a 6809-based system in the past,  I am NOT the right person to do it.)

So what I suggest is :
- I will not make the core evolve beyond this point, as my "editorial" choices would probably be bad in absence of historical knowledge.
- I may try to look at minor problems like the reverse poke, or the interrupt, if this helps, but feel free to rollback anything I wrote you don't agree with, of course, I will not take any offense.

The core will wait for your return for further evolution and I don't see anything wrong with this. It's not like it was almost abandoned like the trs80 model-I was ...

Awaiting your comments ... wish you well ...
Rgds
jF

(p.s. I am french, I may miss some subtleties in the writing ...)

theflynn49, 2025-01-23:
Stan,

Okay, I'll wait for Alan's invite to discord (my login is "theflynn49" alike there). He can send me the link/invite in a private msg on misterfpga.org

Meanwhile, could you send me a link to the symptom/program/test/whatever that shows that interrupt problem ? (or whatever I need to reproduce ?)

> If I came off a little possessive / standoffish - it was not my intent and I apologize and thank you for your continued contributions.

No bad feeling at all,  and blame my 1st msg wording anyway.

jF

shodge12, 2025-01-24:
Invite sent.

-Stan

gyurco, 2025-01-26:
Hi!

I ported this to the SiDi128 FPGA, and just saw that there's a branch here with some fixes.
I did other changes, cleaned up, fixed the SAM (memory size, mpu rate, vclk sync to VDG), added an ACIA, a new FDC, etc... here:
https://github.com/gyurco/CoCo2-FPGA/

theflynn49, 2025-01-26:
Hi @gyurco ! long time no see ...

gyurco, 2025-01-26:
Hi @theflynn49! Yeah, SMS was years ago...

theflynn49, 2025-01-26:
I didn't say thank you for the sources above, so thank you! ... I'm doing a "man git-merge" right now ;)

gyurco, 2025-01-26:
Please test before merging, it was not tried by many users (yet) :)

Closed 2025-03-17.

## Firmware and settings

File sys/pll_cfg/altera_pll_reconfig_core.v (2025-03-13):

// (C) 2001-2017 Intel Corporation. All rights reserved.
// Your use of Intel Corporation's design tools, logic functions and other 
// software and tools, and its AMPP partner logic functions, and any output 
// files any of the foregoing (including device programming or simulation 
// files), and any associated documentation or information are expressly subject 
// to the terms and conditions of the Intel Program License Subscription 
// Agreement, Intel MegaCore Function License Agreement, or other applicable 
// license agreement, including, without limitation, that your use is for the 
// sole purpose of programming logic devices manufactured by Intel and sold by 
// Intel or its authorized distributors.  Please refer to the applicable 
// agreement for further details.


`timescale 1ps/1ps

module altera_pll_reconfig_core
#(
    parameter 	reconf_width       	= 64,
    parameter 	device_family       	= "Cyclone V",
    // MIF Streaming parameters
    parameter   RECONFIG_ADDR_WIDTH     = 6,
    parameter   RECONFIG_DATA_WIDTH     = 32,
    parameter   ROM_ADDR_WIDTH          = 9,
    parameter   ROM_DATA_WIDTH          = 32,
    parameter	ROM_NUM_WORDS           = 512
) ( 

    //input
    input   wire    mgmt_clk,
    input   wire    mgmt_reset,


    //conduits
    output  wire [reconf_width-1:0] reconfig_to_pll,
    input  wire [reconf_width-1:0] reconfig_from_pll,

    // user data (avalon-MM slave interface)
    output  wire [31:0] mgmt_readdata,
    output  wire        mgmt_waitrequest,
    input   wire [5:0]  mgmt_address,
    input   wire        mgmt_read,
    input   wire        mgmt_write,
    input   wire [31:0] mgmt_writedata,

    //other
    output  wire        mif_start_out,
    output  reg [ROM_ADDR_WIDTH-1:0]    mif_base_addr
);
    localparam mode_WR            = 1'b0;
    localparam mode_POLL          = 1'b1;
    localparam MODE_REG           = 6'b000000;
    localparam STATUS_REG         = 6'b000001;
    localparam START_REG          = 6'b000010;
    localparam N_REG              = 6'b000011;
    localparam M_REG              = 6'b000100;
    localparam C_COUNTERS_REG     = 6'b000101;
    localparam DPS_REG            = 6'b000110;
    localparam DSM_REG            = 6'b000111;
    localparam BWCTRL_REG         = 6'b001000;
    localparam CP_CURRENT_REG     = 6'b001001;
    localparam ANY_DPRIO          = 6'b100000;
    localparam CNT_BASE           = 5'b001010;
    localparam VCO_REG              = 6'b011100;
    localparam MIF_REG            = 6'b011111;
    
    //C Counters
    localparam number_of_counters = 5'd18;
    localparam  CNT_0 = 1'd0, CNT_1 = 5'd1, CNT_2 = 5'd2,
                CNT_3 = 5'd3, CNT_4 = 5'd4, CNT_5 = 5'd5,
                CNT_6 = 5'd6, CNT_7 = 5'd7, CNT_8 = 5'd8,
                CNT_9 = 5'd9, CNT_10 = 5'd10, CNT_11 = 5'd11,
                CNT_12 = 5'd12, CNT_13 = 5'd13, CNT_14 = 5'd14,
                CNT_15 = 5'd15, CNT_16 = 5'd16, CNT_17 = 5'd17;
    //C counter addresses
    localparam C_CNT_0_DIV_ADDR = 5'h00;
    localparam C_CNT_0_DIV_ADDR_DPRIO_1 = 5'h11;
    localparam C_CNT_0_3_BYPASS_EN_ADDR = 5'h15;
    localparam C_CNT_0_3_ODD_DIV_EN_ADDR = 5'h17;
    localparam C_CNT_4_17_BYPASS_EN_ADDR = 5'h14;
    localparam C_CNT_4_17_ODD_DIV_EN_ADDR = 5'h16;
    //N counter addresses
    localparam N_CNT_DIV_ADDR = 5'h13;
    localparam N_CNT_BYPASS_EN_ADDR = 5'h15;
    localparam N_CNT_ODD_DIV_EN_ADDR = 5'h17;
    //M counter addresses
    localparam M_CNT_DIV_ADDR = 5'h12;
    localparam M_CNT_BYPASS_EN_ADDR = 5'h15;
    localparam M_CNT_ODD_DIV_EN_ADDR = 5'h17;
    
    //DSM address
    localparam DSM_K_FRACTIONAL_DIVISION_ADDR_0 = 5'h18;
    localparam DSM_K_FRACTIONAL_DIVISION_ADDR_1 = 5'h19;
    localparam DSM_K_READY_ADDR = 5'h17;
    localparam DSM_K_DITHER_ADDR = 5'h17;
    localparam DSM_OUT_SEL_ADDR = 6'h30;
    
    //Other DSM params
    localparam DSM_K_READY_BIT_INDEX = 4'd11;
    //BWCTRL address
    //Bit 0-3 of addr
    localparam BWCTRL_ADDR = 6'h30;
    //CP_CURRENT address
    //Bit 0-2 of addr
    localparam CP_CURRENT_ADDR = 6'h31;
    
    // VCODIV address
    localparam VCO_ADDR = 5'h17;

    localparam DPRIO_IDLE = 3'd0, ONE = 3'd1, TWO = 3'd2, THREE = 3'd3, FOUR = 3'd4,
               FIVE = 3'd5, SIX = 3'd6, SEVEN = 3'd7, EIGHT = 4'd8, NINE = 4'd9, TEN = 4'd10,
               ELEVEN = 4'd11, TWELVE = 4'd12, THIRTEEN = 4'd13, FOURTEEN = 4'd14, DPRIO_DONE = 4'd15;
    localparam IDLE = 2'b00, WAIT_ON_LOCK = 2'b01, LOCKED = 2'b10;
    
    wire            clk;
    wire            reset;
    wire            gnd;

    wire [5: 0]     slave_address;
    wire            slave_read;
    wire            slave_write;
    wire [31: 0]    slave_writedata;

    reg  [31: 0]     slave_readdata_d;
    reg  [31: 0]     slave_readdata_q;
    wire            slave_waitrequest;
    reg             slave_mode;

    assign          clk             = mgmt_clk;
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

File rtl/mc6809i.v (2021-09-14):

`timescale 1ns / 1ns
//////////////////////////////////////////////////////////////////////////////////
// Company: 
// Engineer: Greg Miller
// Copyright (c) 2016, Greg Miller
// 
// Create Date:    14:26:59 08/13/2016 
// Design Name: 
// Module Name:    mc6809 
// Project Name:   Cycle-Accurate 6809 Core 
// Target Devices: 
// Tool versions: 
// Description: 
//
// Dependencies: Intended to be standalone Vanilla Verilog.
//
// Revision: 
// Revision 1.0 - Initial Release
// Additional Comments: 
//
//////////////////////////////////////////////////////////////////////////////////


//
// The 6809 has incomplete instruction decoding.  A collection of instructions, if met, end up actually behaving like
// a binary-adjacent neighbor.  
//
// The soft core permits three different behaviors for this situation, controlled by the instantiation parameter
// ILLEGAL_INSTRUCTIONS
//
// "GHOST" - Mimic the 6809's incomplete decoding.  This is as similar to a hard 6809 as is practical.  [DEFAULT]
//
// "STOP"  - Cause the soft core to cease execution, placing $DEAD on the address bus and R/W to 'read'.  Interrupts,
//           bus control (/HALT, /DMABREQ), etc. are ignored.  The core intentionally seizes in this instance.  
//           (Frankly, this is useful when making changes to the core and you have a logic analyzer connected.)
//
// "IGNORE"- Cause the soft core to merely ignore illegal instructions.  It will consider them 1-byte instructions and
//           attempt to fetch and run an exception 1 byte later.
//

module mc6809i
#(
    parameter ILLEGAL_INSTRUCTIONS="GHOST"
) 
(
    input   clk,
    input   [7:0]  D,
    output  [7:0]  DOut,
    output  [15:0] ADDR,
    output  RnW,
    input   E,
    input   Q,
    output  BS,
    output  BA,
    input   nIRQ,
    input   nFIRQ,
    input   nNMI,
    output  AVMA,
    output  BUSY,
    output  LIC,
    input   nHALT,
    input   nRESET,
    input   nDMABREQ,
    output  [111:0] RegData
);

reg     [7:0]  DOutput;

assign DOut = DOutput;

reg     RnWOut;         // Combinatorial     

reg     rLIC;
assign LIC = rLIC;

reg     rAVMA;
assign AVMA = rAVMA;

reg     rBUSY;
assign BUSY = rBUSY;

// Bus control
// BS    BA
//  0     0   normal (CPU running, CPU is master)
//  0     1   Interrupt Ack
//  1     0   Sync Ack
//  1     1   CPU has gone high-Z on A, D, R/W
//

assign RnW = RnWOut;


/////////////////////////////////////////////////
// Vectors
`define RESET_VECTOR        16'HFFFE
`define NMI_VECTOR          16'HFFFC
`define SWI_VECTOR          16'HFFFA
`define IRQ_VECTOR          16'HFFF8
`define FIRQ_VECTOR         16'HFFF6
`define SWI2_VECTOR         16'HFFF4
`define SWI3_VECTOR         16'HFFF2
`define Reserved_VECTOR     16'HFFF0

//////////////////////////////////////////////////////
// Latched registers
//

// The last-latched copy.
reg     [7:0]           a;
reg     [7:0]           b;
reg     [15:0]          x;
reg     [15:0]          y;
reg     [15:0]          u;
reg     [15:0]          s;
reg     [15:0]          pc;
reg     [7:0]           dp;
reg     [7:0]           cc;
reg     [15:0]          tmp;
reg     [15:0]          addr;
reg     [15:0]          ea;


// Debug ability to export register contents
assign  RegData[7:0] = a;
assign  RegData[15:8] = b;
assign  RegData[31:16] = x;
assign  RegData[47:32] = y;
assign  RegData[63:48] = s;
assign  RegData[79:64] = u;
assign  RegData[87:80] = cc;
assign  RegData[95:88] = dp;
assign  RegData[111:96] = pc;



// The values as being calculated
reg     [7:0]           a_nxt;
reg     [7:0]           b_nxt;
reg     [15:0]          x_nxt;
reg     [15:0]          y_nxt;
reg     [15:0]          u_nxt;
reg     [15:0]          s_nxt;
reg     [15:0]          pc_nxt;
reg     [7:0]           dp_nxt;
reg     [7:0]           cc_nxt;
reg     [15:0]          addr_nxt;
reg     [15:0]          ea_nxt;
reg     [15:0]          tmp_nxt;

reg                     BS_nxt;
reg                     BA_nxt;

// for ADDR, BS/BA, assign them to the flops
assign BS = BS_nxt;
assign BA = BA_nxt;
assign ADDR=addr_nxt;

localparam CC_E=  8'H80;
localparam CC_F=  8'H40;
localparam CC_H=  8'H20;
localparam CC_I=  8'H10;
localparam CC_N=  8'H08;
localparam CC_Z=  8'H04;
localparam CC_V=  8'H02;
localparam CC_C=  8'H01;

localparam CC_E_BIT=  3'd7;
localparam CC_F_BIT=  3'd6;
localparam CC_H_BIT=  3'd5;
localparam CC_I_BIT=  3'd4;
localparam CC_N_BIT=  3'd3;
localparam CC_Z_BIT=  3'd2;
localparam CC_V_BIT=  3'd1;
localparam CC_C_BIT=  3'd0;

// Convenience calculations
reg     [15:0] pc_p1;
reg     [15:0] pc_p2;
reg     [15:0] pc_p3;
reg     [15:0] s_p1;
reg     [15:0] s_m1;
reg     [15:0] u_p1;
reg     [15:0] u_m1;
reg     [15:0] addr_p1;
reg     [15:0] ea_p1;

//////////////////////////////////////////////////////
// NMI Mask
//
// NMI is supposed to be masked - despite the name - until the 6809 loads a value into S.
// Frankly, I'm cheating slightly.  If someone does a LDS #$0, it won't disable the mask.  Pretty much anything else 
// that changes the value of S from the default (which is currently $0) will clear the mask.  A reset will set the mask again.
reg     NMIMask;

reg     NMILatched;
reg     NMISample;
reg     NMISample2;
reg     NMIClear;
reg     NMIClear_nxt;
wire    wNMIClear = NMIClear;

reg     IRQLatched;

reg     IRQSample;
reg     IRQSample2;
reg     FIRQLatched;
reg     FIRQSample;
reg     FIRQSample2;
reg     HALTLatched;
reg     HALTSample;
reg     HALTSample2;
reg     DMABREQLatched;
reg     DMABREQSample;
reg     DMABREQSample2;

// Interrupt types
localparam INTTYPE_NMI      = 3'H0 ;
localparam INTTYPE_IRQ      = 3'H1 ;
localparam INTTYPE_FIRQ     = 3'H2 ;
localparam INTTYPE_SWI      = 3'H3 ;
localparam INTTYPE_SWI2     = 3'H4 ;
localparam INTTYPE_SWI3     = 3'H5 ;

reg [2:0] IntType;
reg [2:0] IntType_nxt;

//////////////////////////////////////////////////////
// Instruction Fetch Details
//
reg     InstPage2;
reg     InstPage3;
reg     InstPage2_nxt;
reg     InstPage3_nxt;

reg     [7:0]        Inst1;
reg     [7:0]        Inst2;
reg     [7:0]        Inst3;
reg     [7:0]        Inst1_nxt;
reg     [7:0]        Inst2_nxt;
reg     [7:0]        Inst3_nxt;


localparam CPUSTATE_RESET      =  7'd0;
localparam CPUSTATE_RESET0     =  7'd1;

localparam CPUSTATE_RESET2     =  7'd3;
localparam CPUSTATE_FETCH_I1   =  7'd4;
localparam CPUSTATE_FETCH_I1V2 =  7'd5;     
localparam CPUSTATE_FETCH_I2   =  7'd8;

localparam CPUSTATE_LBRA_OFFSETLOW =  7'd17;
localparam CPUSTATE_LBRA_DONTCARE  =  7'd18;
localparam CPUSTATE_LBRA_DONTCARE2 =  7'd19;



localparam CPUSTATE_BRA_DONTCARE   =  7'd20;

localparam CPUSTATE_BSR_DONTCARE1  =  7'd21;
localparam CPUSTATE_BSR_DONTCARE2  =  7'd22;
localparam CPUSTATE_BSR_RETURNLOW  =  7'd23;
localparam CPUSTATE_BSR_RETURNHIGH =  7'd24;

localparam CPUSTATE_TFR_DONTCARE1  =  7'd26;
localparam CPUSTATE_TFR_DONTCARE2  =  7'd27;
localparam CPUSTATE_TFR_DONTCARE3  =  7'd28;
localparam CPUSTATE_TFR_DONTCARE4  =  7'd29;
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

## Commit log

2020-11-25 fixed slacks changed clock. turbo graphics fixed
    [dragoncoco.sv]
2020-11-30 Added reset logic when switching machine types
2020-11-30 dragon 64 keyboard works but 64 mode doesn't
    [dragoncoco.sv]
2021-01-11 Add cassette input via the ADC
2021-09-14 floppy and timing fixes
    [dragoncoco.sv, mc6809i.v]
2021-09-14 fixed copy/paste cs problem
    [dragoncoco.sv]
2021-10-26 Added a fix for the dragon64 / dragon64 rom
    [dragoncoco.sv, pia6520.v]
2021-11-17 swapped CPU, fixed wd1793 seek, added dragon disk support
    [dragoncoco.sv, wd1793.sv]
2022-02-07 cassette overlay disk fixes
    Added Cassette Overlay and fixed CoCo disk mistakes
    [dragoncoco.sv]
2024-06-09 CoCo2_20240605 - Joystick & DPAD fix from CoCo3
    CoCo2_20240605
    1. Fixed MiSTer / CoCo2 interface preventing the joysticks ever reaching the
    max value of 63. Specifically '>' was changed to '>=' the DTOA values.
    Additionally, fixed DPAD emulation to reach extremes for all buttoms.
    This is verified in Tandy Diagnostics.
    To Do...
    1: Get FDC working for dragon
    3: Change back to Cycle accurate 09
    4: Add Cassette Save
    5: Update the Template
    6: Add Daily Build Number
    7: Create compatible software tested spreadsheet
    8: Fix double speed poke in the SAM
    [dragoncoco.sv]
2024-06-24 CoCo2_20240622 - 005
    1: Prelim recursion testing spreadsheet completed.
    2: Updated MiSTer template
    3: Added Daily Build Number. Note sys/build_num.tcl changed to add this functionality.
    Updating the template in the future will need to restore this version to prevent
    the loss of this functtion.
    1: Change back to Cycle accurate 09
    2: Add Cassette Save
    3: Fix double speed poke in the SAM
    4: Get FDC working for dragon (edited)
    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
    [COCO2_Testing.xlsx]
2024-07-02 Fixed FDC
    CoCo2_20240701 - 008
    4: Change back to Cycle accurate 09
    5: Fixed Timer [The FDC cartridge does not generate a FIRQ when asserted. This was fixed..]
    6: Preliminary double speed poke in the SAM via SAM registers coded. WIP
    7: FDC changed to use system clk and divide to 8 Mhz changed to /6. FIRQ generation
    for Dragon, qualified enabled only in Dragon configurations.
    Issues:
    1: Highspeed pokes may be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
    [stp1.stp]
2024-12-24 Changes in FDC/Dragon - not working yet
    [dragoncoco.sv]
2024-12-29 Fix Reset (conform to new CPU specs) Fix Turbo mode Fix double-clock and clk_enable
    [dragoncoco.sv]
2025-01-21 Fix video in turbo mode. (#17)
    * typo that broke compile.
    * Fix video in turbo mode.
    - Video is now always 15.4Khz / 58Hz, won't change in turbo mode.
    - ARX/ARY is now only 4/3 or 16/9
    - video sync bug in turbo speed change is fixed. At least I am convinced it is. - Flight.bas runs fine now.
2025-01-27 Misc Fixes to menu, Timer, Added Cassette Write.
    for Dragon, qualified enabled only in Dragon configuratio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
    [ints.stp, stp1.stp]
2025-02-01 Minor update to fix dragon fdc support for OS9
    RC2 for the branch...
    [dragoncoco.sv, wd1793.sv]
2025-02-01 fdc cleanup and fix OS9 Nitro Boot issues.
    RC3 candidate. CoCo2 OS9Nitro now boots.
    [dragoncoco.sv]
2025-02-07 CoCo2_20250207 - 001 RC5
    1: Recursion testing spreadsheet completed.
    4: Changed back to Cycle accurate 09
    6: Double speed poke in the SAM via SAM registers coded. Video sync at high speed fixed
    8: Fixed some incorrect menu sub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
2025-02-07 Releasing RC5 of the CoCo2/Dragon Branch Development
    CoCo2_20250207 - 001 RC5
    for Dragon, qualified enabled only in Dr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
2025-03-13 Doc Updates
    Testing Spreadsheet and added CoCo2 quick reference guide.
    [COCO2_Testing.xlsx]
